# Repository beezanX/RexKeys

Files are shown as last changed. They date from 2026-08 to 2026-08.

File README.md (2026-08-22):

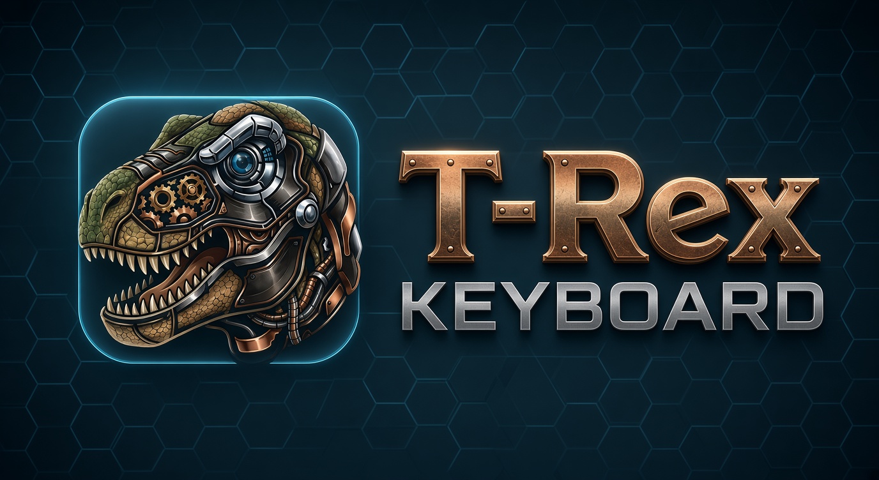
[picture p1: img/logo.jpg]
RexKeys


# RexKeys

I reached a point where I felt empty inside, so I decided to build a custom split keyboard. because why not?

companies like keeb/ZSA....etc prices are skyrocket but the parts cost way less than that BOM might hit only 30usd or less, so clone this repo, and send it to pcbway or any smt pcb assembly supplier

## Parts (per half)

| what | part | qty |
|---|---|---|
| MCU | MDBT50Q-1MV2 (nRF52840) | 1 |
| RGB driver | IS31FL3733 | 1 |
| Battery charger | BQ24074 | 1 |
| USB | USB-C | 1 |
| Switches (Choc hotswap) | SW_Push | 23 |
| Diodes | 1N4148 | 23 |
| RGB LEDs | LED_RGB | 24 |
| Resistors / caps / inductor | R / C / L | a bunch |

## Firmware
ZMK doesn't support the IS31FL3733, so RGB won't work until I add it. Keys work, lights don't. I'm getting there.

## Status

work in progress.

listen to some music
Empire Of The Sun - We Are The People (https://www.youtube.com/watch?v=hN5X4kGhAtU)

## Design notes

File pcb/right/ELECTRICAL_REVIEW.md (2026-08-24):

# Electrical Review — `key_right.kicad_sch`

**Date:** 2026-08-22
**Tool:** KiCad 10.0.3 (`kicad-cli` ERC + manual netlist analysis)
**Board:** Wireless split keyboard, right half (nRF52840 / IS31FL3733 / BQ24074 / USB-C)

## Verdict

**No electrical errors found.** The automated ERC passes with **0 errors**. All power, USB-C,
charger, MCU, I²C and key-matrix circuits were traced in the exported netlist and are wired
correctly. The 73 ERC *warnings* are cosmetic only (stale cached library symbols + one unconfigured
footprint library). A handful of design *considerations* are listed at the end — none are faults.

## What was checked

| Check | Result |
|---|---|
| KiCad ERC (all severities) | 0 errors, 73 warnings (cosmetic) |
| ERC with `single_global_label` re-enabled* | 0 errors — no orphaned/typo'd nets |
| Power-input pins driven (PWR_FLAG coverage) | OK — no undriven power pins |
| Unused pins | 38 No-Connect flags present; ERC clean |
| Manual netlist trace of all critical circuits | OK (details below) |

\* The project had `single_global_label`, `four_way_junction`, and `footprint_filter` set to
*ignore*. Because this design carries **100% of its connectivity through global labels**, a
single-instance label (i.e. a floating pin from a net-name typo) would be invisible. Re-running ERC
with that rule promoted to *error* still produced 0 violations — the net names are consistent.

## Circuit-by-circuit results

**System architecture:** USB-C `+5V` → BQ24074 (U4) power path → `VCC_SYS` → nRF52840 (U2)
internal high-voltage DC/DC (REG0) → `3V3`. LEDs driven from `VCC_SYS` via IS31FL3733 (U3).

- **USB-C (J3):** CC1 and CC2 each have their own **5.1 kΩ Rd to GND** (R2, R3) — correct
  sink/UFP configuration. D+/D− go to nRF pins 35/34 with both orientations tied (A6=B6, A7=B7),
  standard for a USB-2.0-only receptacle. VBUS → nRF pin 32 (5 V-tolerant detect) with 4.7 µF (C6). ✔
- **Charger (BQ24074, U4):** All program pins populated — ISET 590 Ω (≈1.51 A fast charge),
  ILIM 1.1 kΩ (≈1.46 A input limit), ITERM 3.0 kΩ, TMR 46.4 kΩ safety timer, TS 10 kΩ→GND.
  Input (C6 4.7 µF), OUT/`VCC_SYS` (1 µF+4.7 µF+100 nF+10 µF) and BAT (C9 4.7 µF) caps all present. ✔
- **nRF52840 (U2) power:** High-voltage DC/DC mode — VDDH on `VCC_SYS`, DCCH → **10 µH (L2)** →
  VDD (`3V3`). Decoupling: `VCC_SYS` 4.7 µF+100 nF, `3V3` 4.7 µF+1 µF+100 nF. Matches Nordic
  reference. ✔
- **I²C ×2:** LED bus (P0.26/P0.27 ↔ U3) and trackpad bus (P0.22/P0.23 ↔ J4) each have their own
  **4.7 kΩ pull-ups to 3V3** (R9/R10, R5/R6). ✔
- **Status/telemetry:** `BAT_CHG` (open-collector ~CHG) pulled to 3V3 via 10 kΩ; `PGOOD`
  (open-collector) via 100 kΩ; battery sense via 1 MΩ/1 MΩ divider to P0.02 (AIN0); status RGB
  (D50, common-anode to 3V3) sunk through 3×330 Ω to P1.11/12/13. ✔
- **Key matrix:** 6 columns (MCU GPIO → SW pin 1) × 4 rows, with a **per-key diode** (anode at
  switch, cathode to row) on every key — proper N-key-rollout diode matrix. 23 switches / 23 diodes,
  consistent. ✔
- **LED matrix (IS31FL3733):** RSET 20 kΩ, 5 SW rows (LED_R1–R5) × 15 CS columns used; unused
  SW/CS/SYNC/INTB pins No-Connect-flagged. ✔

## Design considerations (not errors)

1. **Charge current ≈1.51 A** (ISET = 590 Ω) sits at the BQ24074's 1.5 A ceiling. Confirm the QFN
   thermal design / charge de-rating at your worst-case (VIN−VBAT) drop.
2. **Input current limit ≈1.46 A** (ILIM = 1.1 kΩ) with **no CC-line current-advertisement
   detection** (CC pins carry only Rd; nothing reads the source's Rp). From a legacy/default USB-C
   source this exceeds the advertised contract. The BQ24074's DPPM prevents brown-out, but it is
   technically out of strict USB-C spec — fine for charging from a proper adapter.
3. **Battery temperature sensing disabled** — TS = 10 kΩ→GND is the datasheet "TS unused" wiring, so
   charging is never gated on battery temperature. Acceptable, but there is no over/under-temp
   charge protection.
4. **`3V3` is sourced entirely from the nRF52840 REG0 output.** Everything on 3V3 (status LED up to
   ~12 mA, trackpad, I²C pull-ups, IS31 digital core) draws from REG0 on top of the MCU's own
   consumption. Verify the external load fits REG0's headroom, particularly during radio TX.
5. **BAT_SENSE divider** has ~500 kΩ source impedance — configure a long SAADC acquisition time (and
   consider a small filter cap to `BAT_SENSE`) for a stable reading.
6. **Cosmetic ERC cleanup:** refresh the cached library symbols (VDD, R_Small, USB_C, LED_RGB show
   `lib_symbol_mismatch`) and add the `axseem` footprint library to project config to clear all 73
   warnings.

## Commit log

2026-08-19 new updates
    [keyboard.kicad_sch]
2026-08-21 power fixed
    [keyboard.kicad_sch]
2026-08-22 battery level and RGB status added merged battery
    [keyboard.kicad_sch]
2026-08-22 upgraded battery to 1.0C rapid-charging
    [keyboard.kicad_sch]
2026-08-22 Add left and right PCB layouts
    [key_left.kicad_pcb, key_left.kicad_sch, key_right.kicad_pcb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]
2026-08-22 Clean up old KiCad files from root directory
    [keyboard.kicad_pcb, keyboard.kicad_sch]
2026-08-24 ERC verified and symbols are added
    [key_left.kicad_sch]
2026-09-01 SWD firmware debug unit added
    [key_left.kicad_sch]
2026-09-06 Firmware reset button added
    [key_left.kicad_sch]
2026-09-07 Trackpad removed for now upon release of version 1.0
    [key_left.kicad_sch]
2026-09-08 Decouplers and CH552 bootloader reset added
    [key_left.kicad_sch]
2026-09-08 USB ESD Protection Added
    [key_left.kicad_sch]
2026-09-08 IS31FL3733 Bulk Decoupling added
    [key_left.kicad_sch]
2026-09-08 Footprints added
    [key_left.kicad_sch]
2026-09-08 Improved IS31FL3733 decouplers AVCC/DVCC pins
    [key_left.kicad_sch]
2026-09-08 Resistor added to BAT_CHG. Schematic ready for PCB placement
    [key_left.kicad_sch]
2026-09-10 LED replacement to Kingbright APTF1616LSEKJ3ZGKQBC
    [key_left.kicad_sch]
